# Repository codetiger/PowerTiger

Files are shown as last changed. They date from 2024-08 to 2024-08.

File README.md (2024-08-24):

# PowerTiger
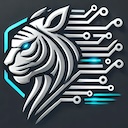
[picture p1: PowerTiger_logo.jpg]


## Overview
This project is an open-source energy monitoring solution designed to track and measure power consumption in a household. The design is centered around the Raspberry Pi Pico W, interfaced with Current Transformer (CT) sensors via a custom PCB. The project is developed using KiCad for PCB design and is part of an open-source hardware (OSH) initiative.

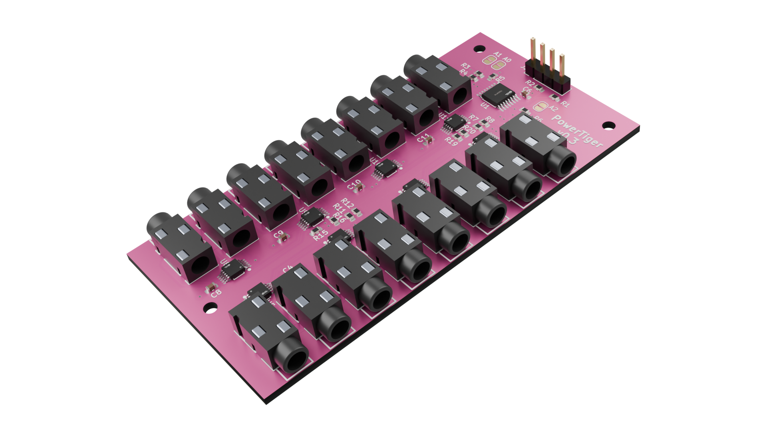
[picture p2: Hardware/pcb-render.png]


## Features
1. Real-time power monitoring: Accurately measure and track power usage in real-time using CT sensors.
2. Wireless communication: The RPi Pico W provides wireless connectivity, enabling easy integration with IoT platforms.
3. Scalable design: Supports multiple CT sensors to monitor different circuits or devices.
4. Open-source hardware and software: The design files and source code are freely available for customization and improvement as part of the OSH initiative.

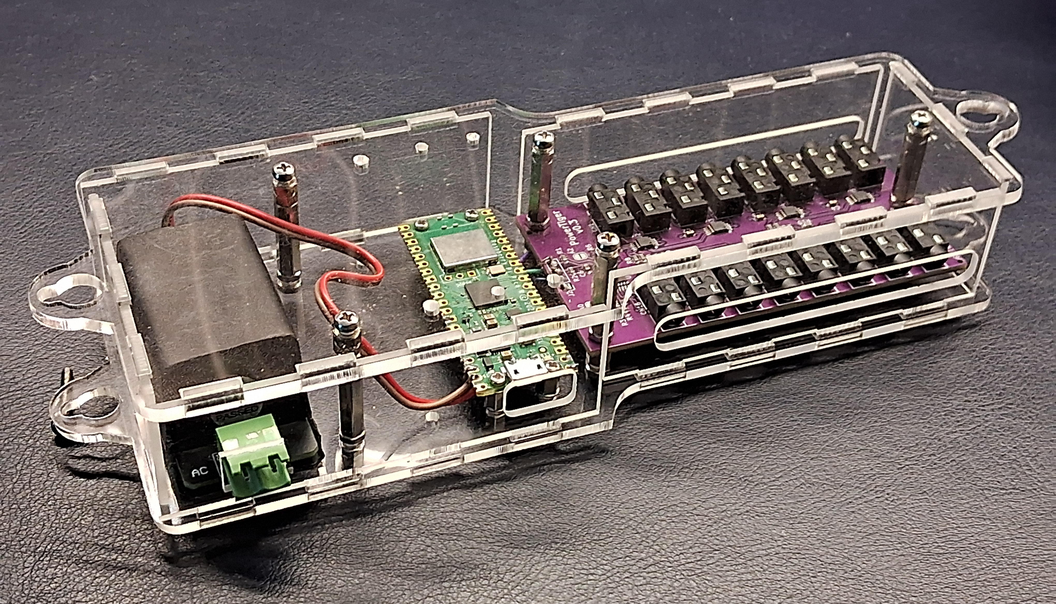
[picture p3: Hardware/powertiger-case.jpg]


## Project Components
* Raspberry Pi Pico W: The microcontroller at the heart of the project, providing processing power and wireless connectivity.
* Custom PCB: Designed in KiCad, this PCB interfaces with the CT sensors for power measurement of various terminals.
* CT Sensors: Used to measure the current flowing through the electrical wires, providing the data needed for power calculation.
* Software: The firmware is written in CircuitPython, running on the RPi Pico W.

| | Components | Count |
|-|---|---|
|1| SCT-013-030 | 5 |
|2| SCT-013-015 | 5 |
|3| SCT-013-005 | 6 |

The json config support configuring 16 CT sensors in any combination as required.

## Grafana Dashboard

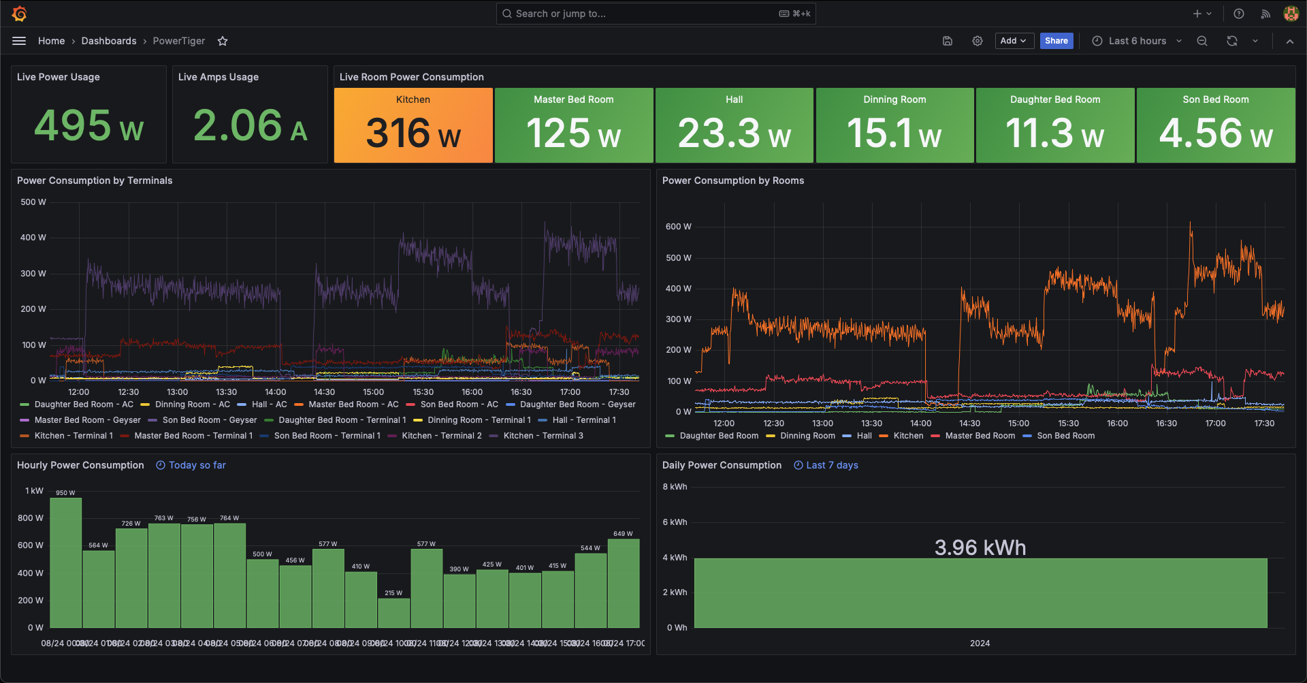
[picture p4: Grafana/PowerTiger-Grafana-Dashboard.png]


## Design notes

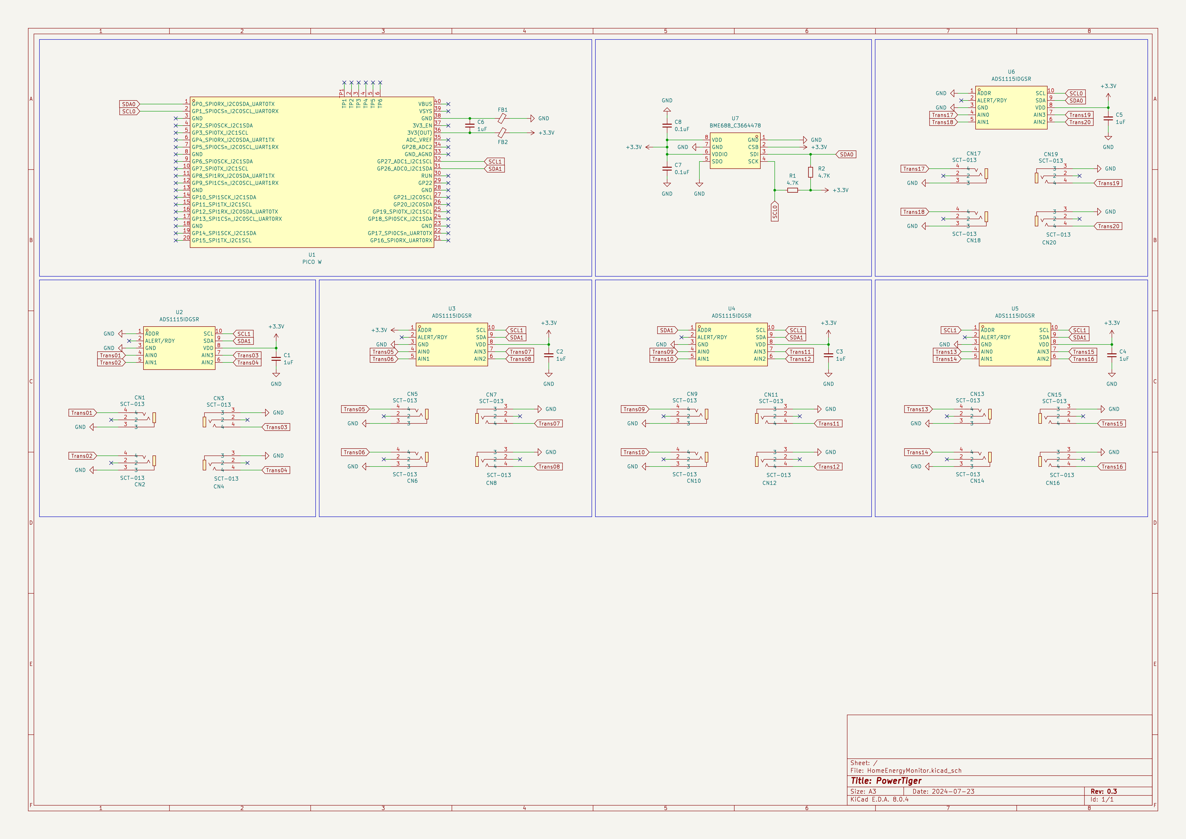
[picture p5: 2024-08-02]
Hardware/schematic.png

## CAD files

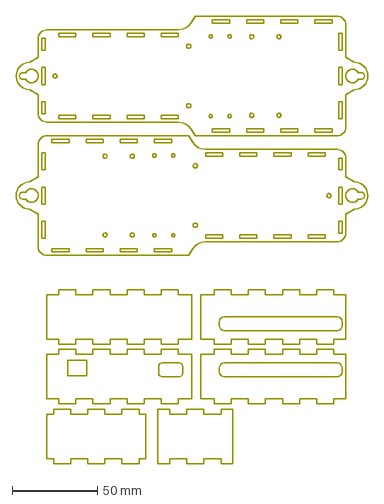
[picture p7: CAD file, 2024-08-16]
Case/PowerTigerCase-plain.dxf
206.0 x 262.0 mm

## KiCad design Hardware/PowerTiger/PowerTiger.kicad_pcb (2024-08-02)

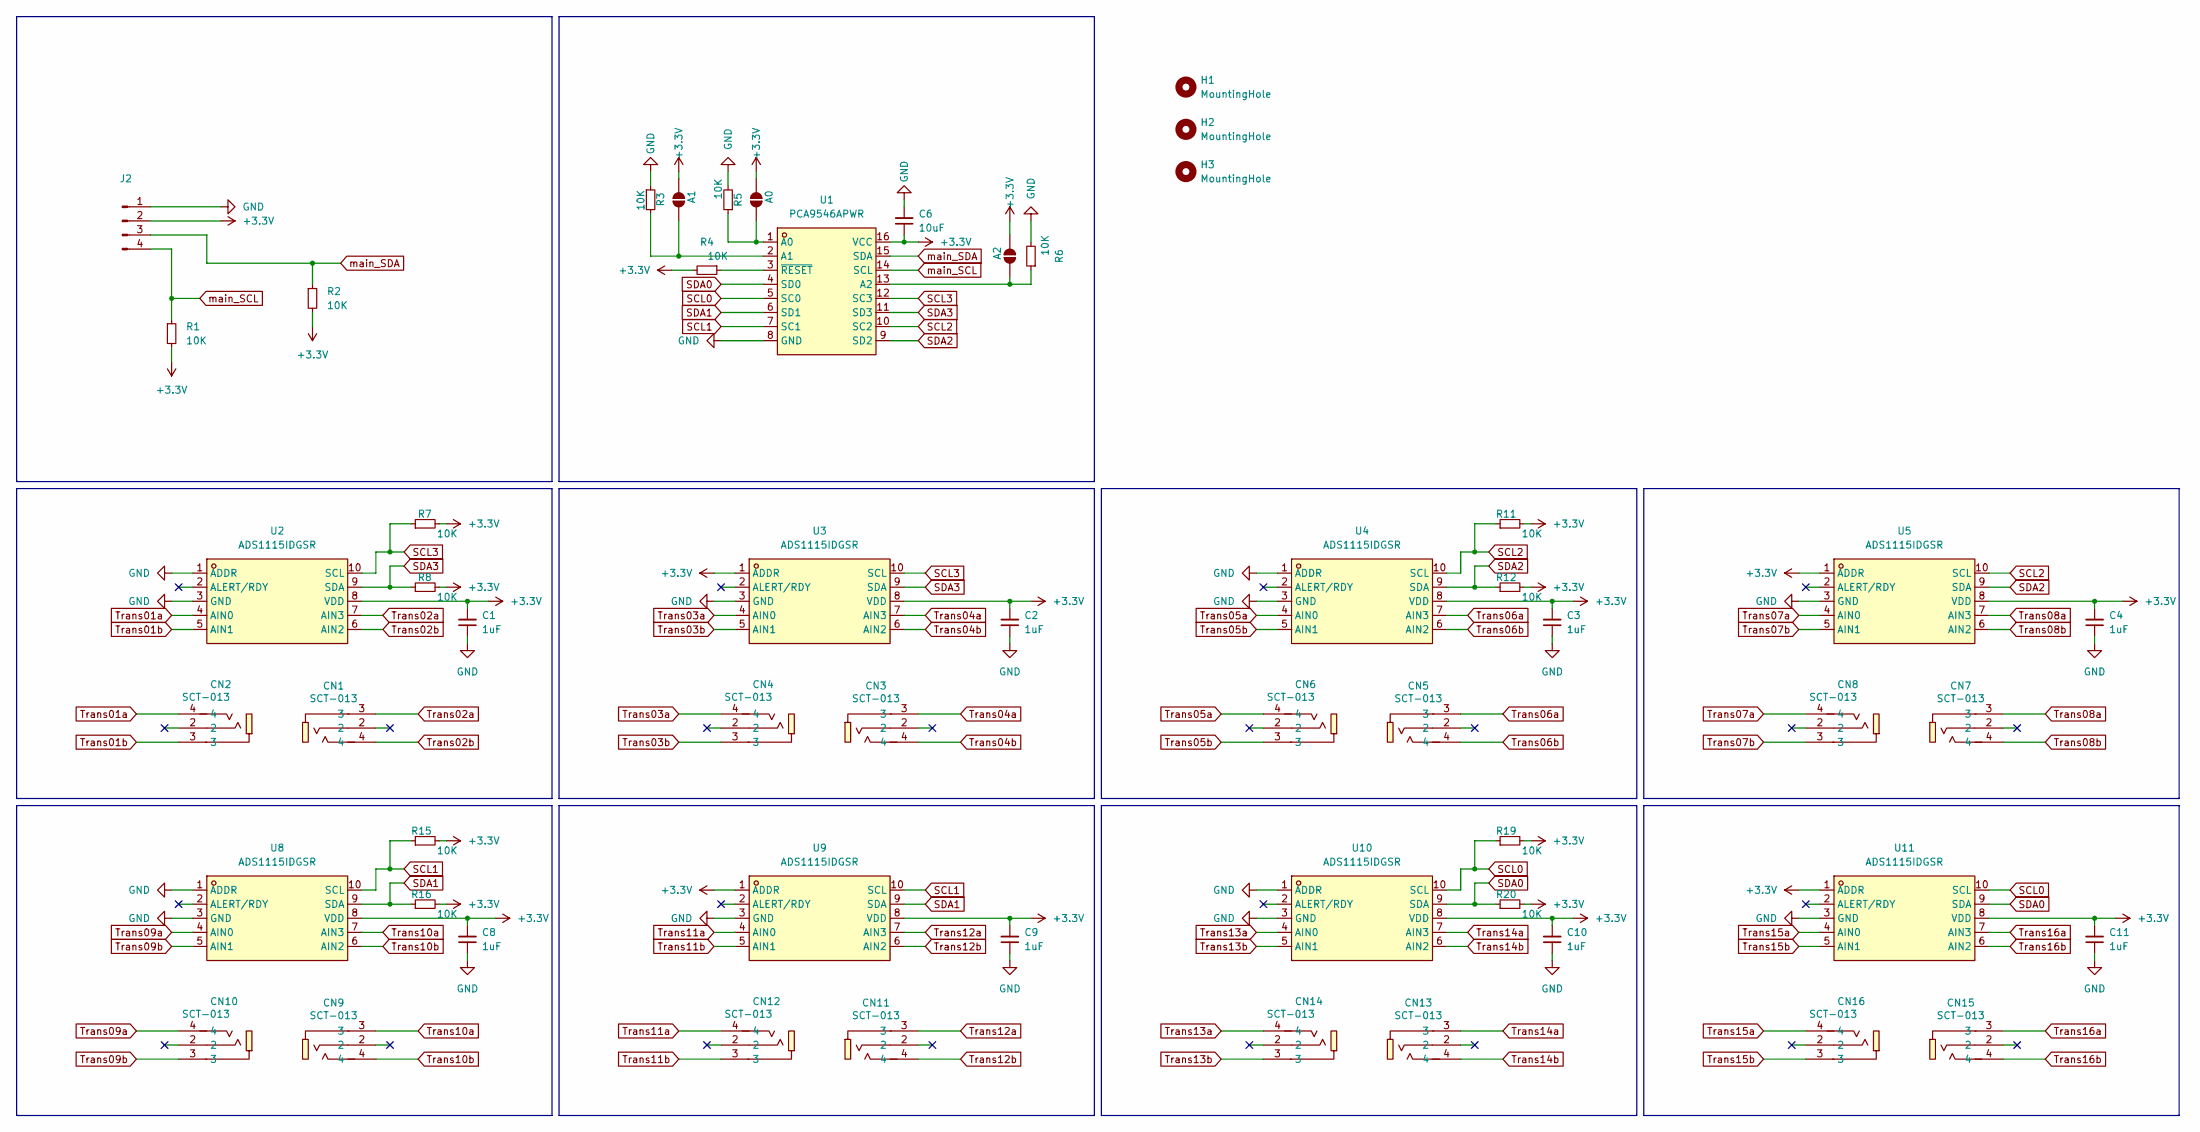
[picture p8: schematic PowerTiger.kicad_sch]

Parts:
A0, A1, A2: SolderJumper_2_Open; SolderJumper-2_P1.3mm_Open_RoundedPad1.0x1.5mm
C1, C2, C3, C4, C8, C9, C10, C11: 1uF; C_0603_1608Metric; Mfr. Part # CL10A105KO8NNNC; LCSC Part C1592
C6: 10uF; C_0603_1608Metric; Mfr. Part # CL10A106MP8NNNC; LCSC Part C85713
CN1, CN2, CN3, CN4, CN5, CN6, CN7, CN8, CN9, CN10, CN11, CN12, CN13, CN14, CN15, CN16: SCT-013; AUDIO-TH_PJ-3200; LCSC Part C2689690
H1, H2, H3: MountingHole; MountingHole_2.5mm
J2: Conn_01x04_Pin; PinHeader_1x04_P2.54mm_Vertical
R1, R2, R3, R4, R5, R6, R7, R8, R11, R12, R15, R16, R19, R20: 10K; R_0603_1608Metric; Mfr. Part # 0603WAF1002T5E; LCSC Part C25804
U1: PCA9546APWR; TSSOP-16_L5.0-W4.4-P0.65-LS6.4-BL; Mfr. Part # PCA9546APWR; LCSC Part C400705
U2, U3, U4, U5, U8, U9, U10, U11: ADS1115IDGSR; MSOP-10_L3.0-W3.0-P0.50-LS5.0-BL; Mfr. Part # ADS1115IDGSR; LCSC Part C37593

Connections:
+3.3V: A0.2 (B), A1.2 (B), A2.2 (B), C1.2, C2.2, C3.2, C4.2, C6.1, C8.2, C9.2, C10.2, C11.2, J2.2, R1.2, R2.2, R4.2, R7.2, R8.2, R11.2, R12.2, R15.2, R16.2, R19.2, R20.2, U1.16 (VCC), U2.8 (VDD), U3.1 (ADDR), U3.8 (VDD), U4.8 (VDD), U5.1 (ADDR), U5.8 (VDD), U8.8 (VDD), U9.1 (ADDR), U9.8 (VDD), U10.8 (VDD), U11.1 (ADDR), U11.8 (VDD)
GND: C1.1, C2.1, C3.1, C4.1, C6.2, C8.1, C9.1, C10.1, C11.1, J2.1, R3.1, R5.2, R6.2, U1.8 (GND), U2.1 (ADDR), U2.3 (GND), U3.3 (GND), U4.1 (ADDR), U4.3 (GND), U5.3 (GND), U8.1 (ADDR), U8.3 (GND), U9.3 (GND), U10.1 (ADDR), U10.3 (GND), U11.3 (GND)
unnamed: A0.1 (A), R5.1, U1.1 (A0)
unnamed: A1.1 (A), R3.2, U1.2 (A1)
unnamed: A2.1 (A), R6.1, U1.13 (A2)
unnamed: R4.1, U1.3 (~RESET)
SCL0: R19.1, U1.5 (SC0), U10.10 (SCL), U11.10 (SCL)
SCL1: R15.1, U1.7 (SC1), U8.10 (SCL), U9.10 (SCL)
SCL2: R11.1, U1.10 (SC2), U4.10 (SCL), U5.10 (SCL)
SCL3: R7.1, U1.12 (SC3), U2.10 (SCL), U3.10 (SCL)
SDA0: R20.1, U1.4 (SD0), U10.9 (SDA), U11.9 (SDA)
SDA1: R16.1, U1.6 (SD1), U8.9 (SDA), U9.9 (SDA)
SDA2: R12.1, U1.9 (SD2), U4.9 (SDA), U5.9 (SDA)
SDA3: R8.1, U1.11 (SD3), U2.9 (SDA), U3.9 (SDA)
Trans01a: CN2.4, U2.4 (AIN0)
Trans01b: CN2.3, U2.5 (AIN1)
Trans02a: CN1.3, U2.7 (AIN3)
Trans02b: CN1.4, U2.6 (AIN2)
Trans03a: CN4.4, U3.4 (AIN0)
Trans03b: CN4.3, U3.5 (AIN1)
Trans04a: CN3.3, U3.7 (AIN3)
Trans04b: CN3.4, U3.6 (AIN2)
Trans05a: CN6.4, U4.4 (AIN0)
Trans05b: CN6.3, U4.5 (AIN1)
Trans06a: CN5.3, U4.7 (AIN3)
Trans06b: CN5.4, U4.6 (AIN2)
Trans07a: CN8.4, U5.4 (AIN0)
Trans07b: CN8.3, U5.5 (AIN1)
Trans08a: CN7.3, U5.7 (AIN3)
Trans08b: CN7.4, U5.6 (AIN2)
Trans09a: CN10.4, U8.4 (AIN0)
Trans09b: CN10.3, U8.5 (AIN1)
Trans10a: CN9.3, U8.7 (AIN3)
Trans10b: CN9.4, U8.6 (AIN2)
Trans11a: CN12.4, U9.4 (AIN0)
Trans11b: CN12.3, U9.5 (AIN1)
Trans12a: CN11.3, U9.7 (AIN3)
Trans12b: CN11.4, U9.6 (AIN2)
Trans13a: CN14.4, U10.4 (AIN0)
Trans13b: CN14.3, U10.5 (AIN1)
Trans14a: CN13.3, U10.7 (AIN3)
Trans14b: CN13.4, U10.6 (AIN2)
Trans15a: CN16.4, U11.4 (AIN0)
Trans15b: CN16.3, U11.5 (AIN1)
Trans16a: CN15.3, U11.7 (AIN3)
Trans16b: CN15.4, U11.6 (AIN2)
main_SCL: J2.4, R1.1, U1.14 (SCL)
main_SDA: J2.3, R2.1, U1.15 (SDA)

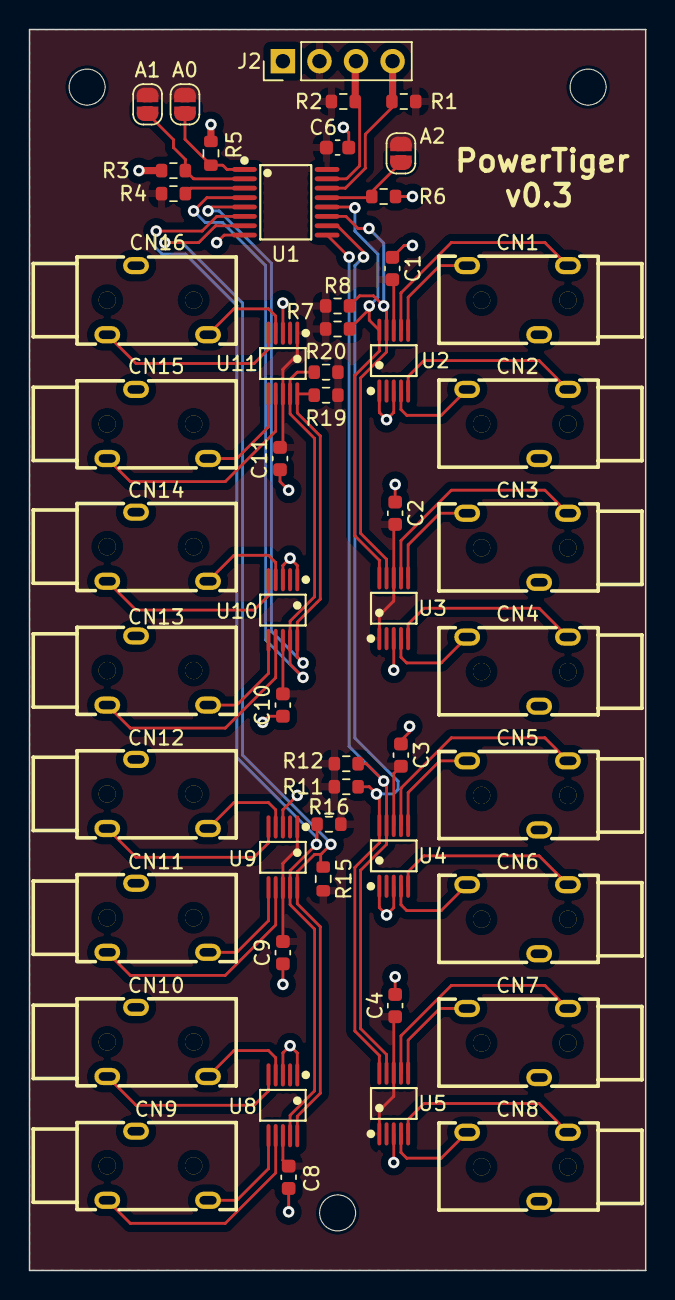
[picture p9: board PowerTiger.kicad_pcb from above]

Board: 2 copper layers, 42.8 x 86.2 mm, 55 parts (0 on the bottom side), 48 nets.

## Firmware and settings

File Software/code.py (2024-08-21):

import time
import json
from math import sqrt
import board
import busio
import microcontroller
import socketpool
import wifi

import adafruit_tca9548a
import adafruit_ads1x15.ads1115 as ADS
from adafruit_ads1x15.ads1x15 import Mode
from adafruit_ads1x15.analog_in import AnalogIn

from adafruit_httpserver import Server, Request, Response

i2c = busio.I2C(scl=board.GP1, sda=board.GP0)
pca = adafruit_tca9548a.PCA9546A(i2c)

def load_json_file(path):
    with open(path) as fh:
        j_obj = json.load(fh)
    return j_obj
        
sensor_info = load_json_file("devices.json")

addresses = [0x48, 0x49]
channels = [(ADS.P2, ADS.P3), (ADS.P0, ADS.P1)]
current_sensors = []
for i in reversed(range(4)):
    for address in addresses:
        for channel in channels:
            current_sensors.append({"pca_channel": i, "ads_address": address, "ads_channel": channel})

SAMPLE_DURATION = 80
RATE = 860

def setup_sensor_objects():
    for channel in range(4):
        for address in addresses:
            ads = ADS.ADS1115(pca[channel], address=address, gain=4)
            ads.data_rate = RATE
            ads.mode = Mode.CONTINUOUS

            for sensor in current_sensors:
                if sensor['pca_channel'] == channel and sensor['ads_address'] == address:
                    ads_channel = sensor["ads_channel"]
                    sensor["ads_channel_object"] = AnalogIn(ads, ads_channel[0], ads_channel[1])
                    _ = sensor["ads_channel_object"].value

def update_voltage_reading():
    samples = int(SAMPLE_DURATION * RATE / 1000) + 1
    for sensor in current_sensors:
        sensor['data'] = 0

    for i in range(samples):
        for sensor in current_sensors:
            if sensor["ads_channel"] == (ADS.P0, ADS.P1):
                sct_device = sensor["ads_channel_object"]
                sensor['data'] += sct_device.voltage ** 2

    for i in range(samples):
        for sensor in current_sensors:
            if sensor["ads_channel"] == (ADS.P2, ADS.P3):
                sct_device = sensor["ads_channel_object"]
                sensor['data'] += sct_device.voltage ** 2

    for sensor in current_sensors:
        sensor['data'] = sqrt( sensor['data'] / samples )

def get_data():
    html = '# PowerTiger - Home Energy Consumption Metrics\n'
    html += 'cpu_temperature{{device="CPU"}} {}\n'.format(microcontroller.cpu.temperature)
    update_voltage_reading()
    for idx, sensor in enumerate(current_sensors):
        s_info = sensor_info[idx]
        sct_sensor = sensor["ads_channel_object"]
        vname = (s_info["room"] + " " + s_info["device"]).replace(" ", "_").lower()
        amps = int(sensor['data'] * s_info["maxamps"] * 1000)
        html += '{}{{room="{}",device="{}"}} {}\n'.format(vname, s_info["room"], s_info["device"], amps)

    return html

setup_sensor_objects()

pool = socketpool.SocketPool(wifi.radio)
server = Server(pool, "/metrics", debug=True)

@server.route("/metrics", append_slash=True)
def metrics_handler(request: Request):
    return Response(request, body=get_data(), content_type="text/plain")

server.serve_forever(str(wifi.radio.ipv4_address))

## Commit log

2024-08-02 Working PCB and CircuitPython application for Prometheus exporter
    [HomeEnergyMonitor.kicad_pcb, HomeEnergyMonitor.kicad_sch, bom.csv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]
2024-08-16 Completed working version hw, sw and case
    [HomeEnergyMonitor.kicad_pcb, HomeEnergyMonitor.kicad_sch, PowerTiger.kicad_pcb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]
2024-08-21 Externalise device config for easy of config
2024-08-24 Added Logo for PowerTiger
